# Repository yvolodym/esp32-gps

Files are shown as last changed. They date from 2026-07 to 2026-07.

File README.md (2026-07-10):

# esp32-gps

Akku-betriebenes GNSS-Empfänger-Board auf Basis des **ESP32**. Ein GNSS-Modul (GPS/BDS/GLONASS)
liefert die Positionsdaten, der ESP32 liest sie über UART aus und stellt sie per **Bluetooth**
für andere Geräte (z. B. Smartphone, Laptop, Navigationssoftware) bereit.

> Aktueller Stand: vollständiges KiCad-Hardwaredesign (Schaltplan + Platinenlayout). Die
> ESP32-Firmware (ESP-IDF) liest das GNSS-Modul per UART aus und gibt die NMEA-Sätze aktuell
> im Log aus; die Weiterleitung per Bluetooth folgt als nächster Schritt.

## Features

- **ESP32-PICO-V3** als zentrale MCU (WLAN + Bluetooth Classic/BLE integriert)
- **Ai-Thinker GP-01** GNSS-Modul (GPS/BDS/GLONASS) mit externer Antenne (Koax-Anschluss)
- **USB-C** für Programmierung (über integrierten CH340C USB-UART-Wandler) und zum Laden
- **Li-Ion-Akkubetrieb** (18650) mit Lade-IC TP4056, Akkuschutz (DW01A) und automatischer
  Umschaltung zwischen USB- und Akkuversorgung (LTC4412 Ideal-Diode-Power-Path)
- 3,3-V-Logikversorgung über AP2112K-3.3-LDO, ESD-Schutz am USB-Eingang

## Hardware

| Schaltplan | Inhalt |
|---|---|
| `kicad/esp32-gps.kicad_sch` | ESP32-PICO-V3, GNSS-Modul GP-01, USB-UART (CH340C), Antennenanschluss |
| `kicad/supply.kicad_sch` | Akku, Ladeschaltung, Power-Path, 3,3-V-Regler |
| `kicad/esp32-gps.kicad_pcb` | Platinenlayout |

Erstellt mit KiCad 9. Verwendete Zusatzbibliothek: [`yvolodym/kicad-libraries`](https://github.com/yvolodym).

## Firmware

ESP-IDF-Projekt (Framework-Version 6.0.2), Ziel-Chip `esp32`. Initialisiert UART2 auf den
Pins, die im Schaltplan als `GPS_TX`/`GPS_RX` verdrahtet sind (IO25/IO26), liest die NMEA-Sätze
des GP-01 zeilenweise ein und gibt sie per `ESP_LOGI` aus.

```
main/
  main.c          UART-Init + Log-Ausgabe der NMEA-Sätze
  CMakeLists.txt
CMakeLists.txt     Projekt-Root (ESP-IDF)
sdkconfig.defaults
```

Bauen/Flashen:

```sh
. $IDF_PATH/export.sh
idf.py set-target esp32
idf.py build
idf.py -p /dev/ttyUSB0 flash monitor
```

## Repo-Struktur

```
kicad/
  esp32-gps.kicad_pro   Projektdatei
  esp32-gps.kicad_sch   Hauptschaltplan
  supply.kicad_sch      Stromversorgung/Ladeschaltung
  esp32-gps.kicad_pcb   Platinenlayout
main/                   ESP-IDF-Firmware (GNSS-UART, aktuell Log-Ausgabe)
```

## Status / Roadmap

- [x] Schaltplan (MCU, GNSS, USB, Stromversorgung)
- [x] Platinenlayout
- [x] Firmware: GNSS-UART auslesen, NMEA-Sätze im Log ausgeben
- [ ] Bestückungsliste (BOM) / Fertigungsvorbereitung
- [ ] Firmware: NMEA-Daten per Bluetooth (SPP/BLE) bereitstellen
- [ ] Gehäuse

## Mitwirken

Projektsprache ist Deutsch – Commits, Issues und Doku bitte auf Deutsch verfassen.

Weitere Hinweise für die Arbeit mit Claude Code an diesem Projekt siehe [`CLAUDE.md`](./CLAUDE.md).

## Lizenz

Dieses Projekt steht unter der [CERN Open Hardware Licence Version 2 - Strongly Reciprocal
(CERN-OHL-S-2.0)](./LICENSE), einer verbreiteten Copyleft-Lizenz für offene Hardwareprojekte.

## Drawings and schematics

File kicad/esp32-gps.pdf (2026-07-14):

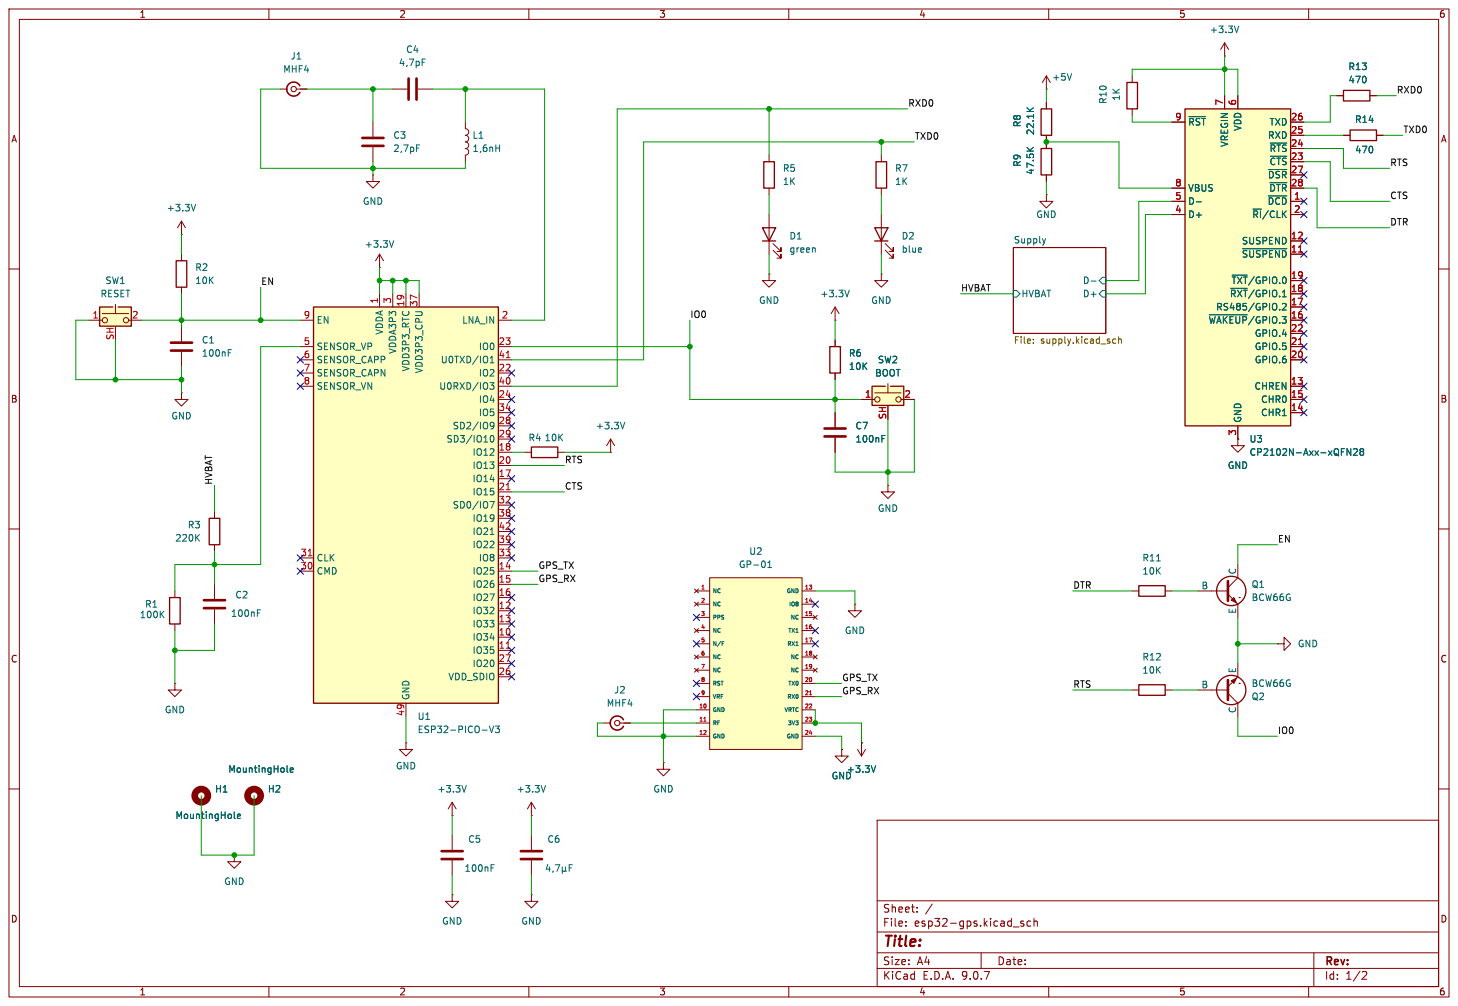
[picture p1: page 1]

3 TXD 26 RXD 25 ~{RTS} 24 ~{CTS} 23 ~{DSR} 27 ~{DTR} 28 ~{DCD}1 ~{RI}/CLK2 SUSPEND 12 ~{SUSPEND}11 ~{TXT}/GPIO.019 ~{RXT}/GPIO.118 RS485/GPIO.2 17 ~{WAKEUP}/GPIO.316 GPIO.4 22 GPIO.5 21 GPIO.6 20 CHREN 13 CHR0 15 CHR1 14 U3 CP2102N-Axx-xQFN28 C1

3 TXD 26 RXD 25 ~{RTS} 24 ~{CTS} 23 ~{DSR} 27 ~{DTR} 28 ~{DCD}1 ~{RI}/CLK2 SUSPEND 12 ~{SUSPEND}11 ~{TXT}/GPIO.019 ~{RXT}/GPIO.118 RS485/GPIO.2 17 ~{WAKEUP}/GPIO.316 GPIO.4 22 GPIO.5 21 GPIO.6 20 CHREN 13 CHR0 15 CHR1 14 GND

Id: 1/2 Title: File: esp32-gps.kicad_sch Sheet: /

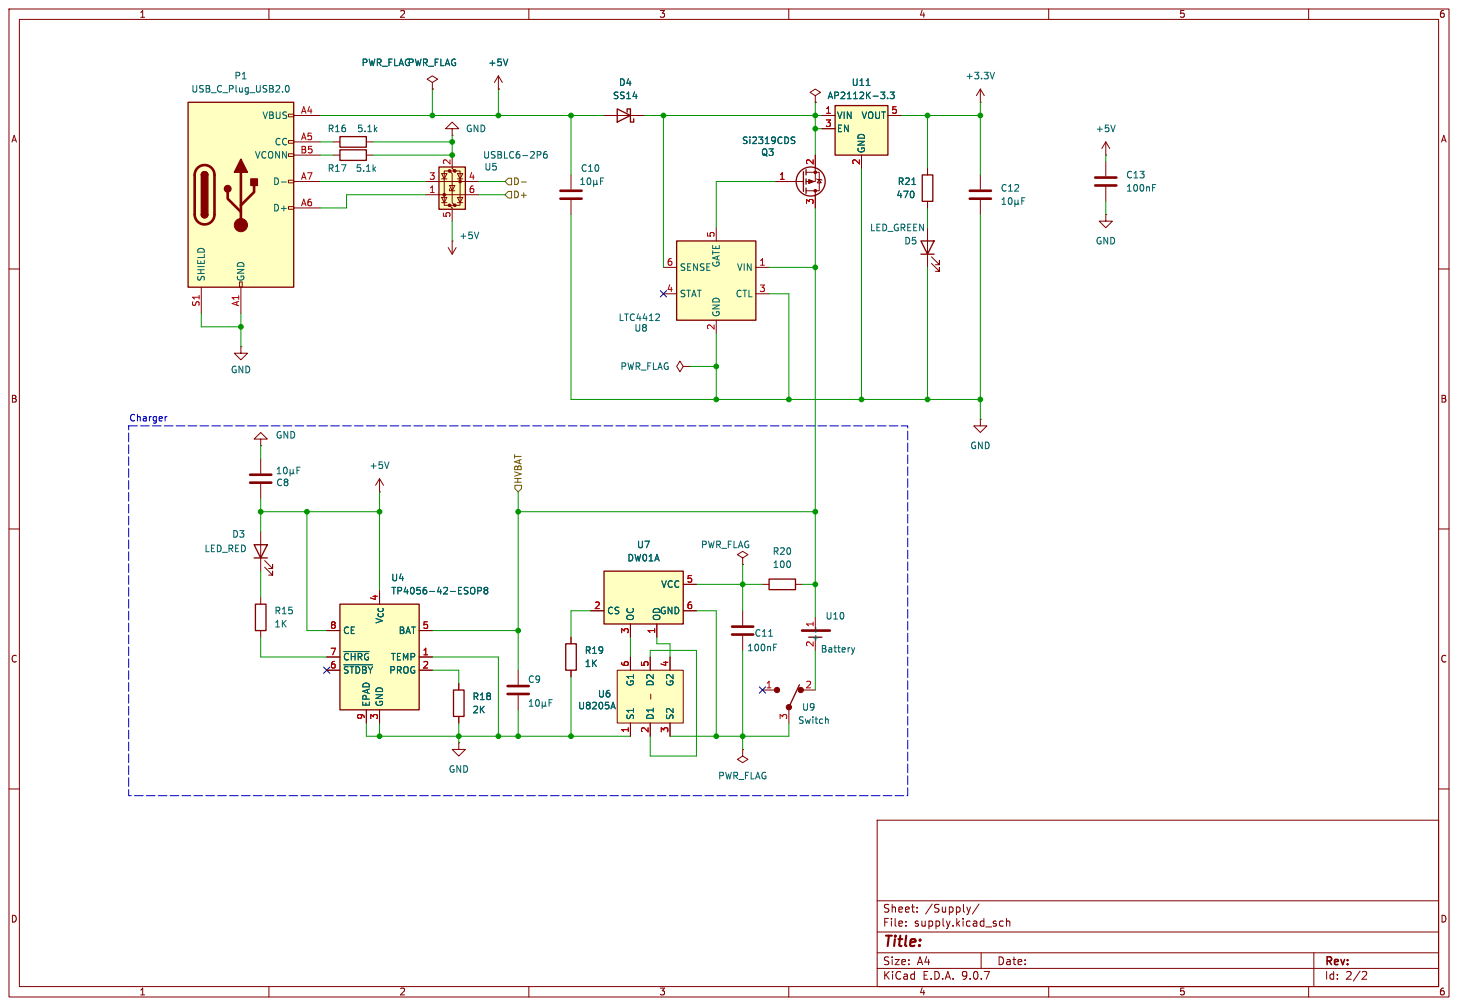
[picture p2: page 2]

3 BAT 5 TEMP 1 PROG 2 U4 TP4056-42-ESOP8 GND

Id: 2/2 Title: File: supply.kicad_sch Sheet: /Supply/ 1

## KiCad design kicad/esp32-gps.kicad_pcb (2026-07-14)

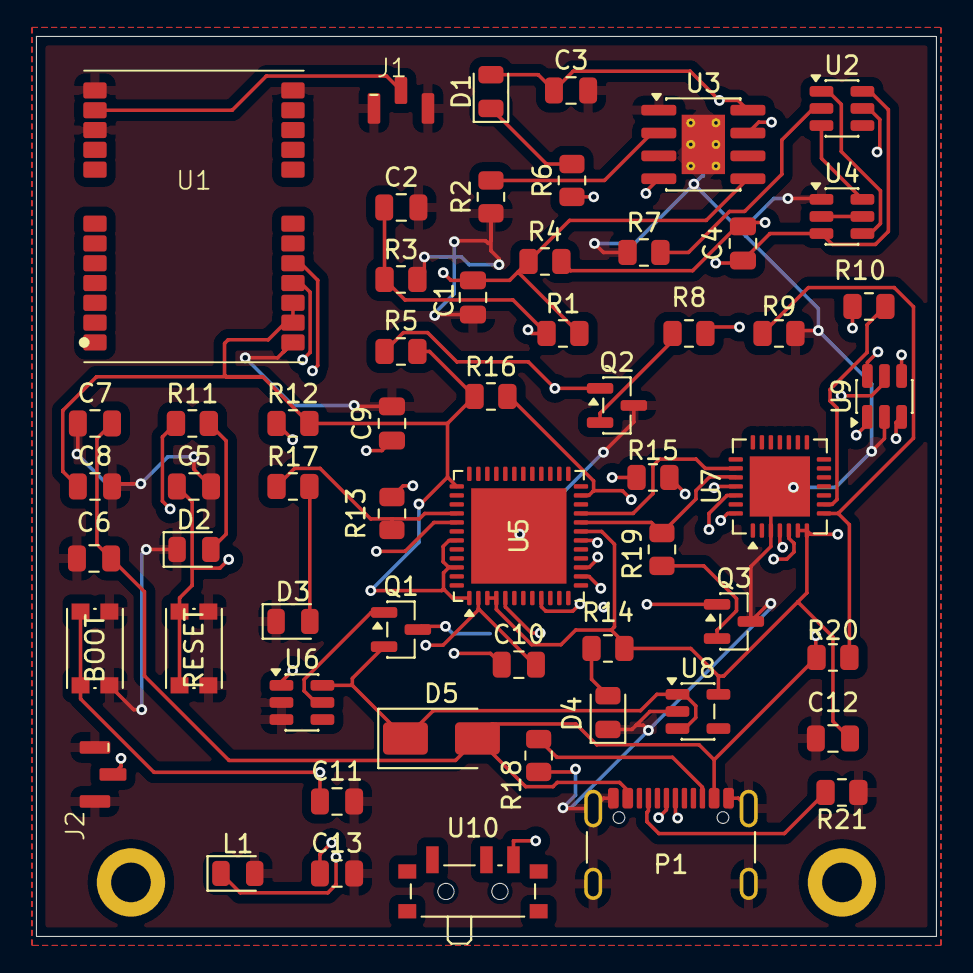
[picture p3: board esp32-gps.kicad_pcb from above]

Board: 4 copper layers, 50.0 x 50.0 mm, 61 parts (1 on the bottom side), 45 nets.

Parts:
C1, C3, C6, C12: 10µF; C_0805_2012Metric
C2, C4, C5, C7, C11, C13: 100nF; C_0805_2012Metric
C8: 4,7µF; C_0805_2012Metric
C9: 2,7pF; C_0805_2012Metric
C10: 4,7pF; C_0805_2012Metric
D1: LED_RED; D_0805_2012Metric
D2: blue; D_0805_2012Metric
D3: green; D_0805_2012Metric
D4: LED_GREEN; D_0805_2012Metric
D5: SS14; D_SMA
H1, H2: MountingHole; MountingHole_2.2mm_M2_DIN965_Pad
J1, J2: MHF4
L1: 1,6nH; D_0805_2012Metric
P1: USB_C_Plug_USB2.0; USB_C_Receptacle_GCT_USB4105-xx-A_16P_TopMnt_Horizontal
Q1: Si2319CDS; SOT-23
Q2, Q3: BCW66G; SOT-23
R1: 220K; R_0805_2012Metric
R2: 2K; R_0805_2012Metric
R3: 100K; R_0805_2012Metric
R4: 100; R_0805_2012Metric
R5, R8, R12, R16, R19: 10K; R_0805_2012Metric
R6, R7, R10, R11, R17: 1K; R_0805_2012Metric
R9: 47.5K; R_0805_2012Metric
R13, R14, R15: 470; R_0805_2012Metric
R18, R21: 5.1k; R_0805_2012Metric
R20: 22.1K; R_0805_2012Metric
SW1: BOOT; SW_Push_1P1T_NO_CK_KMR2
SW2: RESET; SW_Push_1P1T_NO_CK_KMR2
U1: GP-01
U2: DW01A; SOT-23-6
U3: TP4056-42-ESOP8; SOIC-8-1EP_3.9x4.9mm_P1.27mm_EP2.41x3.3mm_ThermalVias
U4: U8205A; SOT-23-6
U5: ESP32-PICO-V3; QFN-48-1EP_7x7mm_P0.5mm_EP5.3x5.3mm
U6: LTC4412; TSOT-23-6
U7: CP2102N-Axx-xQFN28; QFN-28-1EP_5x5mm_P0.5mm_EP3.35x3.35mm
U8: AP2112K-3.3; SOT-23-5
U9: USBLC6-2P6; SOT-23-6
U10: Switch; SW_SPDT_PCM12
U11: Battery; CR2032

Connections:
+3.3V: C8.1, C12.1, C13.1, R5.1, R10.2, R12.2, R14.1, R16.1, U1.22 (VRTC), U1.23 (3V3), U5.1 (VDDA), U5.3 (VDDA3P3), U5.4 (VDDA3P3), U5.19 (VDD3P3_RTC), U5.37 (VDD3P3_CPU), U5.43 (VDDA), U5.46 (VDDA), U7.6 (VDD), U7.7 (VREGIN), U8.5 (VOUT)
+5V: C3.1, C6.1, C7.2, D1.2 (A), D5.2 (A), P1.A4 (VBUS), P1.A9 (VBUS), P1.B4 (VBUS), P1.B9 (VBUS), R20.2, U3.4 (V_{CC}), U3.8 (CE), U9.5 (VBUS)
/CTS: U5.21 (IO15), U7.23 (~CTS)
/DTR: R8.1, U7.28 (~DTR)
/EN: C5.1, Q2.1 (C), R5.2, SW2.2, U5.9 (EN)
/GPS_RX: U1.21 (RX0), U5.15 (IO26)
/GPS_TX: U1.20 (TX0), U5.14 (IO25)
/HVBAT: C1.1, Q1.3 (D), R1.2, R4.1, U3.5 (BAT), U6.1 (VIN), U11.1 (+)
/IO0: C11.1, Q3.1 (C), R16.2, SW1.1, U5.23 (IO0)
/RTS: R19.1, U5.20 (IO13), U7.24 (~RTS)
/RXD0: R13.2, R17.1, U5.40 (U0RXD/IO3)
/Supply/D+: U7.4 (D+), U9.6 (I/O1)
/Supply/D-: U7.5 (D-), U9.4 (I/O2)
/TXD0: R11.1, R15.2, U5.41 (U0TXD/IO1)
GND: C1.2, C2.2, C3.2, C5.2, C6.2, C7.1, C8.2, C9.2, C11.2, C12.2, C13.2, D2.1 (K), D3.1 (K), D4.1 (K), J1.2 (GND), J2.2 (GND), L1.2, P1.A1 (GND), P1.A12 (GND), P1.B1 (GND), P1.B12 (GND), P1.S1 (SHIELD), Q2.3 (E), Q3.3 (E), R2.1, R3.2, R7.1, R9.1, R18.2, R21.2, SW1.2, SW2.1, U1.10 (GND), U1.12 (GND), U1.13 (GND), U1.24 (GND), U3.1 (TEMP), U3.3 (GND), U3.9 (EPAD), U4.1 (S1), U5.49 (GND), U6.2 (GND), U6.3 (CTL), U7.3 (GND), U7.29 (GND), U8.2 (GND), U9.2 (GND)
unnamed: D3.2 (A), R17.2
unnamed: D2.2 (A), R11.2
unnamed: D1.1 (K), R6.2
unnamed: D5.1 (K), Q1.2 (S), U6.6 (SENSE), U8.1 (VIN), U8.3 (EN)
unnamed: D4.2 (A), R14.2
unnamed: C9.1, C10.1, J2.1 (SIGNAL)
unnamed: J1.1 (SIGNAL), U1.11 (RF)
unnamed: P1.A5 (CC), R21.1
unnamed: P1.A6 (D+), U9.1 (I/O1)
unnamed: P1.A7 (D-), U9.3 (I/O2)
unnamed: P1.B5 (VCONN), R18.1
unnamed: Q2.2 (B), R8.2
unnamed: Q3.2 (B), R19.2
unnamed: Q1.1 (G), U6.5 (GATE)
unnamed: R12.1, U5.18 (IO12)
unnamed: C10.2, L1.1, U5.2 (LNA_IN)
unnamed: C2.1, R1.1, R3.1, U5.5 (SENSOR_VP)
unnamed: R15.1, U7.25 (RXD)
unnamed: R13.1, U7.26 (TXD)
unnamed: R9.2, R20.1, U7.8 (VBUS)
unnamed: R10.1, U7.9 (~RST)
unnamed: R2.2, U3.2 (PROG)
unnamed: R6.1, U3.7 (~CHRG)
unnamed: U4.2 (D1), U4.5 (D2)
unnamed: U2.3 (OC), U4.6 (G1)
unnamed: U2.1 (OD), U4.4 (G2)
unnamed: C4.1, U2.6 (GND), U4.3 (S2), U10.3
unnamed: R7.2, U2.2 (CS)
unnamed: C4.2, R4.2, U2.5 (VCC)
unnamed: U10.2, U11.2 (-)

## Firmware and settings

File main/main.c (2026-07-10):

#include <stdio.h>
#include <string.h>

#include "freertos/FreeRTOS.h"
#include "freertos/task.h"
#include "driver/uart.h"
#include "esp_log.h"

// UART-Verbindung zum GNSS-Modul (Ai-Thinker GP-01, UART0/TX0-RX0).
// Siehe kicad/esp32-gps.kicad_sch: Netze GPS_TX / GPS_RX.
#define GPS_UART_PORT      UART_NUM_2
#define GPS_UART_RX_PIN    25  // ESP32 IO25 <- GP-01 TX0 (Netz GPS_TX)
#define GPS_UART_TX_PIN    26  // ESP32 IO26 -> GP-01 RX0 (Netz GPS_RX)
#define GPS_UART_BAUD_RATE 9600
#define GPS_UART_RX_BUF_SIZE 1024

static const char *TAG = "gps";

static void gps_uart_init(void)
{
    const uart_config_t uart_config = {
        .baud_rate = GPS_UART_BAUD_RATE,
        .data_bits = UART_DATA_8_BITS,
        .parity    = UART_PARITY_DISABLE,
        .stop_bits = UART_STOP_BITS_1,
        .flow_ctrl = UART_HW_FLOWCTRL_DISABLE,
        .source_clk = UART_SCLK_DEFAULT,
    };

    ESP_ERROR_CHECK(uart_driver_install(GPS_UART_PORT, GPS_UART_RX_BUF_SIZE, 0, 0, NULL, 0));
    ESP_ERROR_CHECK(uart_param_config(GPS_UART_PORT, &uart_config));
    ESP_ERROR_CHECK(uart_set_pin(GPS_UART_PORT, GPS_UART_TX_PIN, GPS_UART_RX_PIN,
                                  UART_PIN_NO_CHANGE, UART_PIN_NO_CHANGE));
}

// Liest Bytes vom GNSS-UART, sammelt sie zeilenweise (NMEA-Sätze enden mit \r\n)
// und gibt jede vollständige Zeile per ESP_LOGI aus.
static void gps_uart_task(void *arg)
{
    uint8_t byte;
    char line[128];
    size_t line_len = 0;

    while (1) {
        int read = uart_read_bytes(GPS_UART_PORT, &byte, 1, pdMS_TO_TICKS(1000));
        if (read <= 0) {
            continue;
        }

        if (byte == '\n') {
            if (line_len > 0 && line[line_len - 1] == '\r') {
                line_len--;
            }
            line[line_len] = '\0';
            if (line_len > 0) {
                ESP_LOGI(TAG, "%s", line);
            }
            line_len = 0;
            continue;
        }

        if (line_len < sizeof(line) - 1) {
            line[line_len++] = (char)byte;
        } else {
            // Zeile zu lang (kein gueltiger NMEA-Satz) - verwerfen und neu beginnen.
            line_len = 0;
        }
    }
}

void app_main(void)
{
    gps_uart_init();
    ESP_LOGI(TAG, "GPS-UART auf UART%d initialisiert (RX=IO%d, TX=IO%d, %d Baud)",
             GPS_UART_PORT, GPS_UART_RX_PIN, GPS_UART_TX_PIN, GPS_UART_BAUD_RATE);

    xTaskCreate(gps_uart_task, "gps_uart_task", 4096, NULL, 10, NULL);
}
